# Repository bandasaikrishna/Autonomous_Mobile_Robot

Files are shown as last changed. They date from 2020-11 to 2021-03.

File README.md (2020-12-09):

## Autonomous Navigation Mobile Robot using ROS Navigation Stack.
Watch the video tutorial [here .](https://youtu.be/Uz_i_sjVhIM)
Website documentation [here.](https://www.rosroboticslearning.com/)

AMCL is used for localisation, with DWA local planner planner for path planning.

### Sensors used:
1. RP Lidar A1-M8.
2. Motor Encoders.

### Other parts:
1. Nvidia Jetson Nano 4gb.
2. 2x Arduino nano (One for each motor to make sure smooth operation of Interrupt service routine to count the encoder pulses and ROS communication over I2C.)
3. Encoder motors [Link Here](https://robokits.co.in/motors/rhino-gb37-12v-dc-geared-motor/dc-12v-encoder-servo-motors/rhino-gb37-12v-60rpm-10.4kgcm-dc-geared-encoder-servo-motor)
4. Robot Chasis
5. Boost converter to provide 12V for motors.

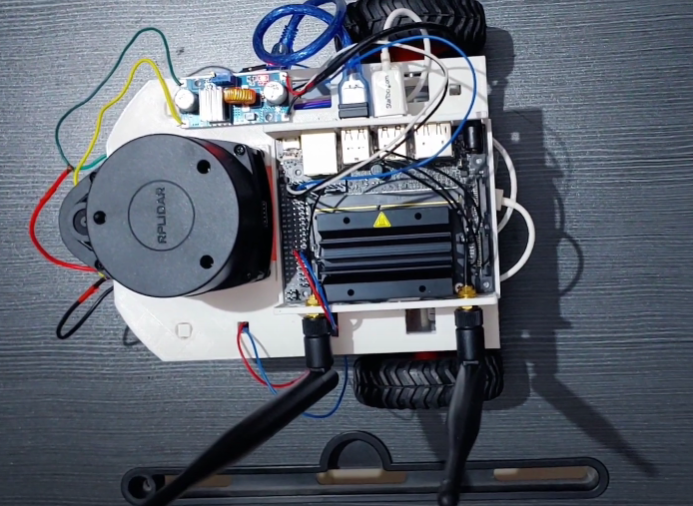
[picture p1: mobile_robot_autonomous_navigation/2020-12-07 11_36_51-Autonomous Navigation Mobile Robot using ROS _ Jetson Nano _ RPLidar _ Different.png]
Jetson Nano and LiDAR

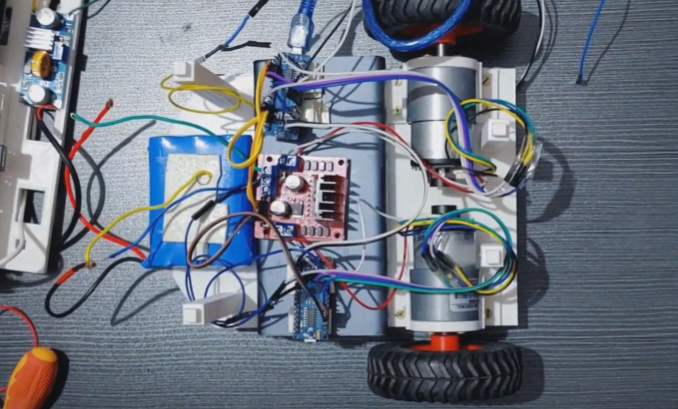
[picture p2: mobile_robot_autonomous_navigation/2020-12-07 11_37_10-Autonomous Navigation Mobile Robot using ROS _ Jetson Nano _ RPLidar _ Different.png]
Arduinos and motors


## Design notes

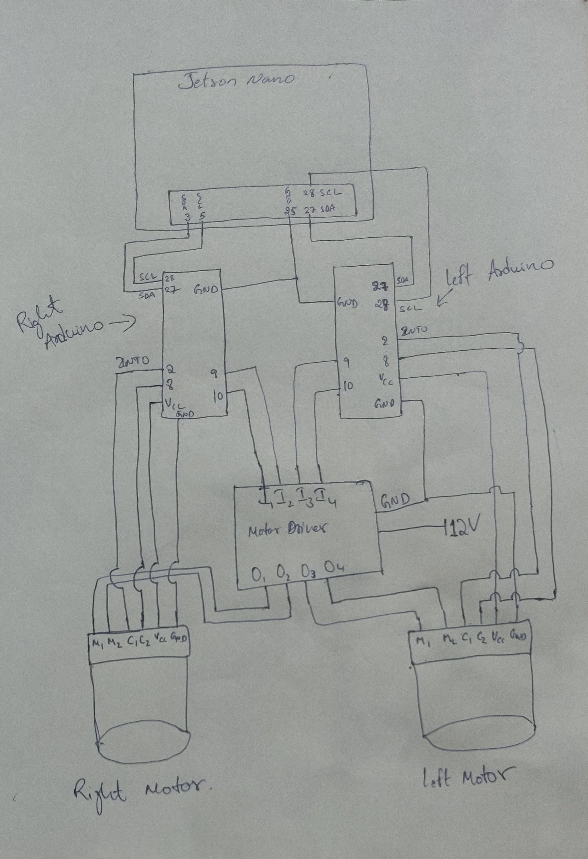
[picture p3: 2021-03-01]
mobile_robot_autonomous_navigation/Connection_Diagram.jpg

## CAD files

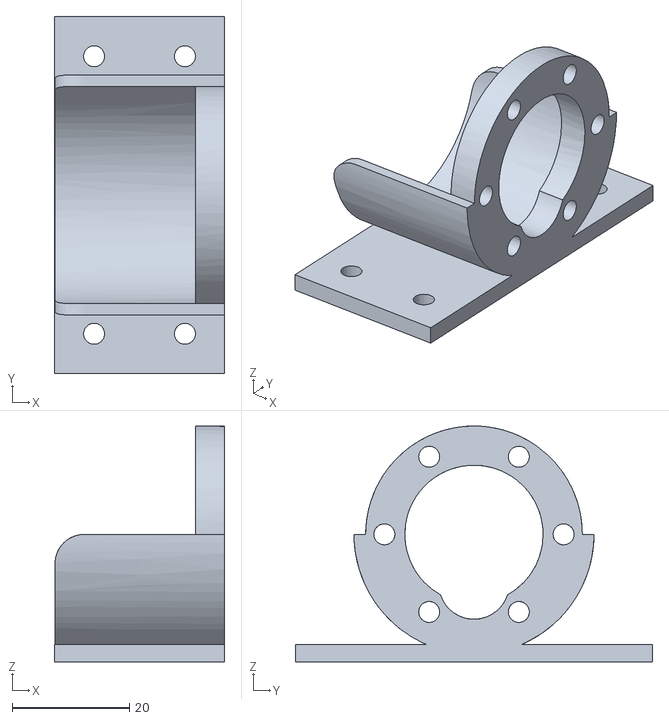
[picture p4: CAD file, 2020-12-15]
3D_Model_Files/Mobile_robot_Motor_case.stl
29.1 x 61.0 x 40.3

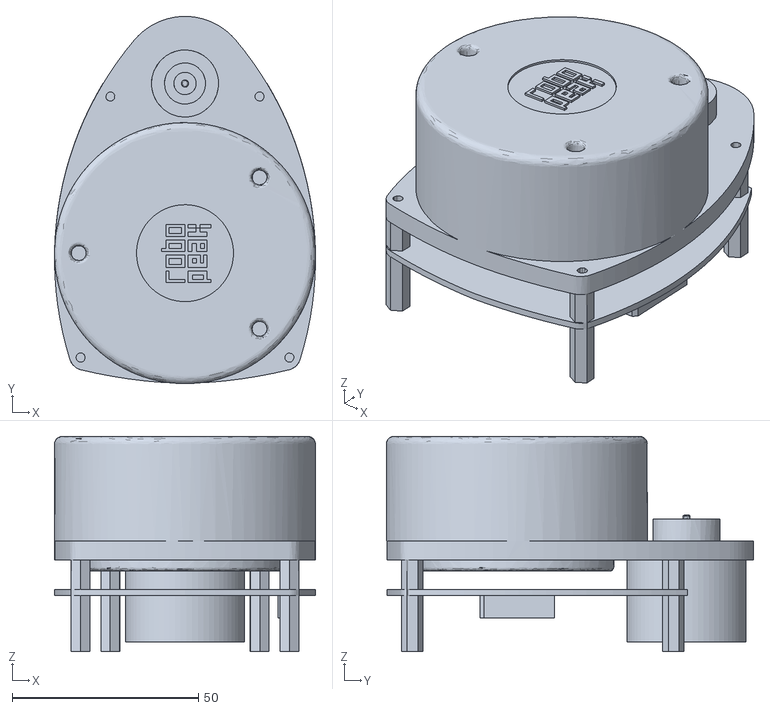
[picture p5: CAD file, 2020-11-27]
mobile_robot_autonomous_navigation/stl/RpLidar.stl
70.0 x 98.5 x 57.7

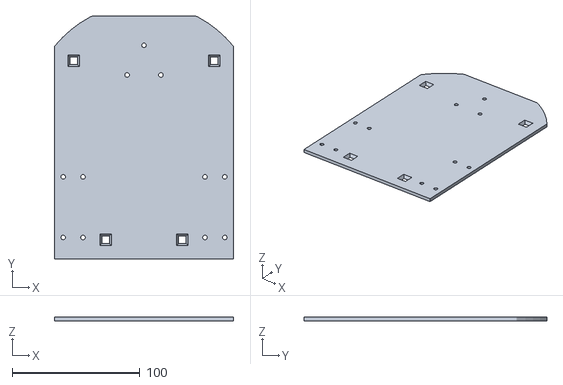
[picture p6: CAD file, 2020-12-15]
3D_Model_Files/Mobile_robot_base.stl
140.0 x 190.0 x 3.00

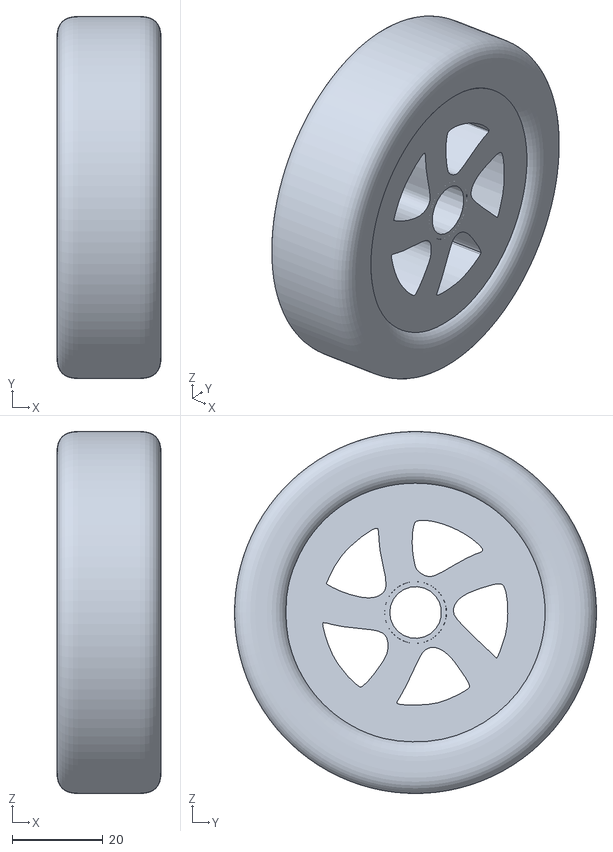
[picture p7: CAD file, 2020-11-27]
mobile_robot_autonomous_navigation/stl/Wheel.stl
23.0 x 80.0 x 80.0

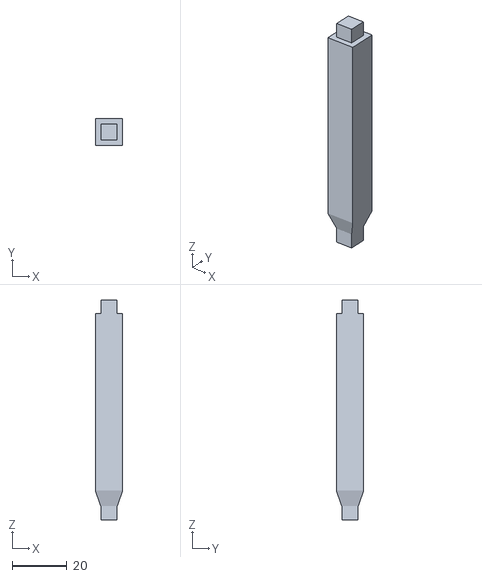
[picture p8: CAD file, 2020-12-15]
3D_Model_Files/Support_rod.stl
10.0 x 10.0 x 80.0

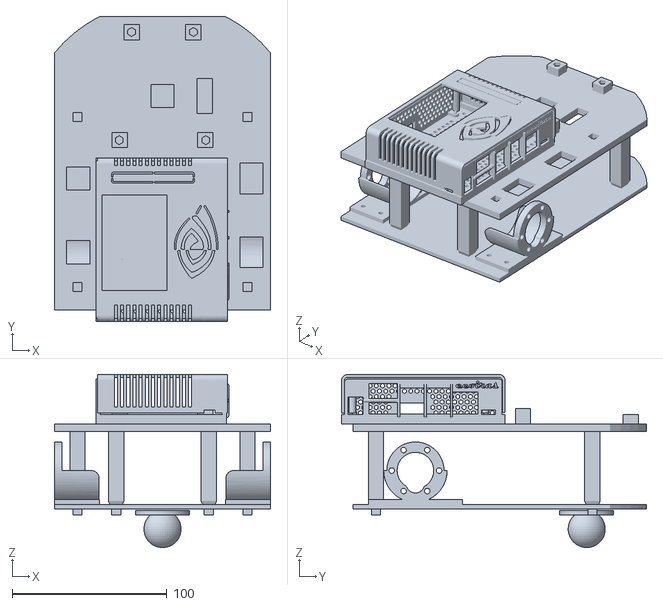
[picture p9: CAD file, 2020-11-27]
mobile_robot_autonomous_navigation/stl/Chasis.stl
140.0 x 197.3 x 112.0

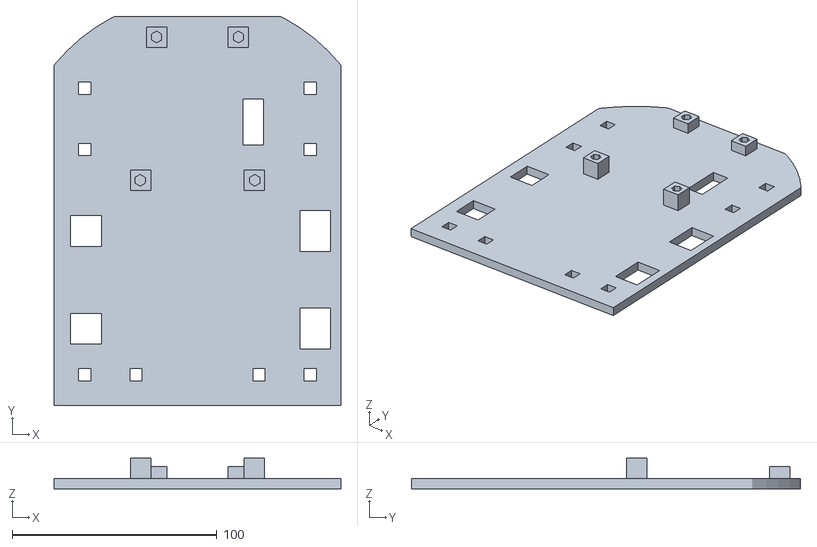
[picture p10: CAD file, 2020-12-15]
3D_Model_Files/Mobile_robot_2nd_base.stl
140.0 x 190.0 x 15.0

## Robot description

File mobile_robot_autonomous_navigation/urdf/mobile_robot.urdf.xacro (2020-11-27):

<?xml version="1.0"?>
<robot name="mobile_robot" xmlns:xacro="http://ros.org/wiki/xacro">

    <material name="blue">
	    <color rgba="0 0 0.8 1"/>
    </material>

    <material name="white">
	    <color rgba="1 1 1 1"/>
    </material>

    <material name="black">
	    <color rgba="0 0 0 1"/>
    </material>

    <material name="green">
        <color rgba="0.0 0.8 0.0 1.0"/>
    </material>

    <link name="base_link">
        <!--<visual>
          <geometry>
             <box size="0.24 0.24 0.001"/>
          </geometry>
          <material name="white"/>
          <origin rpy="0 0 0" xyz="0 0 0.0005"/>
          <material>
            <color rgba="0 0 0.8 1" />
          </material>
        </visual> -->
        <collision>
          <origin rpy="0 0 0" xyz="0 0 0.0005"/>
          <geometry>
            <box size="0.22 0.22 0.001"/>
          </geometry>
        </collision>
    </link>

    <joint name="base_link_joint" type="fixed">
        <origin xyz="0 0 0.026" rpy="0 0 -1.5708" />
        <parent link="base_link" />
        <child link="base_plate" />
    </joint>

    <link name="base_plate">
    <visual>
      <origin rpy="0 0 0" xyz="0.03 0 -0.026"/>
      <geometry>
        <mesh filename="package://mobile_robot_autonomous_navigation/stl/Chasis.stl" scale="0.001 0.001 0.001"/> 
      </geometry>
      <material name="white"/>
    </visual>
    <collision>
      <origin rpy="0 0 0" xyz="0.03 0 -0.026" />
      <geometry>
        <mesh filename="package://mobile_robot_autonomous_navigation/stl/Chasis.stl" scale="0.001 0.001 0.001" />
      </geometry>
    </collision>
    </link>   
    
    
    <joint name="right_wheel_joint" type="continuous">
        <origin xyz="-0.08 -0.06 0.015" rpy="0 0 0" />
        <parent link="base_plate" />
        <child link="right_wheel" />
        <axis xyz="-1 0 0" />
    </joint>

    <link name="right_wheel">
    <visual>
      <origin rpy="0 0 0" xyz="0.11 0.059 -0.04"/>
      <geometry>
        <mesh filename="package://mobile_robot_autonomous_navigation/stl/Wheel.stl" scale="0.001 0.001 0.001"/> 
      </geometry>
      <material name="black"/>
    </visual>
    <collision>
      <origin rpy="0 0 0" xyz="0.11 0.059 -0.04"/>
      <geometry>
        <mesh filename="package://mobile_robot_autonomous_navigation/stl/Wheel.stl" scale="0.001 0.001 0.001" />
      </geometry>
    </collision>
    </link>   
    
    <joint name="left_wheel_joint" type="continuous">
        <origin xyz="0.08 -0.06 0.015" rpy="0 0 0" />
        <parent link="base_plate" />
        <child link="left_wheel" />
        <axis xyz="-1 0 0" />
    </joint>

    <link name="left_wheel">
    <visual>
      <origin rpy="0 0 0" xyz="0.133 0.059 -0.04"/>
      <geometry>
        <mesh filename="package://mobile_robot_autonomous_navigation/stl/Wheel.stl" scale="0.001 0.001 0.001"/> 
      </geometry>
      <material name="black"/>
    </visual>
    <collision>
      <origin rpy="0 0 0" xyz="0.133 0.059 -0.04"/>
      <geometry>
        <mesh filename="package://mobile_robot_autonomous_navigation/stl/Wheel.stl" scale="0.001 0.001 0.001" />
      </geometry>
    </collision>
    </link>   
    
    <joint name="laser_joint" type="fixed">
        <origin xyz="0 0.040 0.090" rpy="0 0 1.5708" />
        <parent link="base_plate" />
        <child link="laser" />
    </joint>

    <link name="laser">
    <visual>
      <origin rpy="0 0 -1.5708" xyz="0.084 -0.242 -0.098"/>
      <geometry>
        <mesh filename="package://mobile_robot_autonomous_navigation/stl/RpLidar.stl" scale="0.001 0.001 0.001"/> 
      </geometry>
      <material name="blue"/>
    </visual>
    <collision>
      <origin rpy="0 0 0" xyz="0.242 0.084 -0.098" />
      <geometry>
        <mesh filename="package://mobile_robot_autonomous_navigation/stl/RpLidar.stl" scale="0.001 0.001 0.001" />
      </geometry>
    </collision>
    </link>  
    
</robot>

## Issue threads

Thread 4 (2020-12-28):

Issues in case of controller_check.launch

vijaybande, 2020-12-28:
while running controller_check.launch I am getting
" Device File not available. Aborting read"

yuki-ubuntu, 2021-03-19:
I am also suffering from the same error.

```
... logging to /home/user/.ros/log/24fe7864-888a-11eb-bda4-bb6933ebd3a4/roslaunch-user-3515.log
Checking log directory for disk usage. This may take a while.
Press Ctrl-C to interrupt
Done checking log file disk usage. Usage is <1GB.

started roslaunch server http://user:39347/

SUMMARY
========

PARAMETERS
 * /joint_limits/left_wheel_joint/has_acceleration_limits: False
 * /joint_limits/left_wheel_joint/has_effort_limits: False
 * /joint_limits/left_wheel_joint/has_jerk_limits: False
 * /joint_limits/left_wheel_joint/has_position_limits: False
 * /joint_limits/left_wheel_joint/has_velocity_limits: True
 * /joint_limits/left_wheel_joint/max_acceleration: 0.0
 * /joint_limits/left_wheel_joint/max_effort: 0
 * /joint_limits/left_wheel_joint/max_jerk: 0
 * /joint_limits/left_wheel_joint/max_position: 0
 * /joint_limits/left_wheel_joint/max_velocity: 2.62
 * /joint_limits/left_wheel_joint/min_effort: 0
 * /joint_limits/left_wheel_joint/min_position: 0
 * /joint_limits/left_wheel_joint/min_velocity: -2.62
 * /joint_limits/right_wheel_joint/has_acceleration_limits: False
 * /joint_limits/right_wheel_joint/has_effort_limits: False
 * /joint_limits/right_wheel_joint/has_jerk_limits: False
 * /joint_limits/right_wheel_joint/has_position_limits: False
 * /joint_limits/right_wheel_joint/has_velocity_limits: True
 * /joint_limits/right_wheel_joint/max_acceleration: 0.0
 * /joint_limits/right_wheel_joint/max_effort: 0
 * /joint_limits/right_wheel_joint/max_jerk: 0
 * /joint_limits/right_wheel_joint/max_position: 0
 * /joint_limits/right_wheel_joint/max_velocity: 2.62
 * /joint_limits/right_wheel_joint/min_effort: 0
 * /joint_limits/right_wheel_joint/min_position: 0
 * /joint_limits/right_wheel_joint/min_velocity: -2.62
 * /mobile_robot/joints_update/publish_rate: 50
 * /mobile_robot/joints_update/type: joint_state_contr...
 * /mobile_robot/mobile_base_controller/angular/z/has_acceleration_limits: True
 * /mobile_robot/mobile_base_controller/angular/z/has_jerk_limits: True
 * /mobile_robot/mobile_base_controller/angular/z/has_velocity_limits: True
 * /mobile_robot/mobile_base_controller/angular/z/max_acceleration: 0.5
 * /mobile_robot/mobile_base_controller/angular/z/max_jerk: 1
 * /mobile_robot/mobile_base_controller/angular/z/max_velocity: 1.0472
 * /mobile_robot/mobile_base_controller/base_frame_id: base_link
 * /mobile_robot/mobile_base_controller/cmd_vel_timeout: 0.25
 * /mobile_robot/mobile_base_controller/left_wheel: left_wheel_joint
 * /mobile_robot/mobile_base_controller/linear/x/has_acceleration_limits: True
 * /mobile_robot/mobile_base_controller/linear/x/has_jerk_limits: False
 * /mobile_robot/mobile_base_controller/linear/x/has_velocity_limits: True
 * /mobile_robot/mobile_base_controller/linear/x/max_acceleration: 0.025
 * /mobile_robot/mobile_base_controller/linear/x/max_jerk: 2.0
 * /mobile_robot/mobile_base_controller/linear/x/max_velocity: 0.1
 * /mobile_robot/mobile_base_controller/linear/x/min_acceleration: -0.025
 * /mobile_robot/mobile_base_controller/linear/x/min_velocity: -0.1
 * /mobile_robot/mobile_base_controller/pose_covariance_diagonal: [0.001, 0.001, 10...
 * /mobile_robot/mobile_base_controller/publish_rate: 50.0
 * /mobile_robot/mobile_base_controller/right_wheel: right_wheel_joint
 * /mobile_robot/mobile_base_controller/twist_covariance_diagonal: [0.001, 0.001, 10...
 * /mobile_robot/mobile_base_controller/type: diff_drive_contro...
 * /mobile_robot/mobile_base_controller/wheel_radius: 0.04
 * /mobile_robot/mobile_base_controller/wheel_radius_multiplier: 1.0
 * /mobile_robot/mobile_base_controller/wheel_separation: 0.18
 * /mobile_robot/mobile_base_controller/wheel_separation_multiplier: 1.0
 * /robot_description: <?xml version="1....
 * /rosdistro: noetic
 * /rosversion: 1.15.9

NODES
  /
    controller_spawner (controller_manager/spawner)
    robot_hardware_interface (mobile_robot_autonomous_navigation/mobile_robot_hardware_interface)
    robot_state_publisher (robot_state_publisher/robot_state_publisher)
    rviz (rviz/rviz)

auto-starting new master
process[master]: started with pid [3525]
ROS_MASTER_URI=http://localhost:11311

setting /run_id to 24fe7864-888a-11eb-bda4-bb6933ebd3a4
process[rosout-1]: started with pid [3535]
started core service [/rosout]
process[robot_hardware_interface-2]: started with pid [3542]
process[robot_state_publisher-3]: started with pid [3543]
process[rviz-4]: started with pid [3544]
[ERROR] [1616141251.262584453]: Couldn't open I2C Bus 0 [openfd():open 2]
[ERROR] [1616141251.269328046]: I2C slave 8 failed [openfd():ioctl 9]
[ERROR] [1616141251.269863482]: Couldn't open I2C Bus 1 [openfd():open 13]
[ERROR] [1616141251.269956203]: I2C slave 9 failed [openfd():ioctl 9]
process[controller_spawner-5]: started with pid [3550]
[ERROR] [1616141251.627434753]: Device File not available. Aborting read
[ERROR] [1616141251.627596250]: Device File not available. Aborting read
[ERROR] [1616141251.727291223]: Device File not available. Aborting read
[ERROR] [1616141251.727414425]: Device File not available. Aborting read
[ERROR] [1616141251.827256932]: Device File not available. Aborting read
[ERROR] [1616141251.827378319]: Device File not available. Aborting read
[ERROR] [1616141251.927267288]: Device File not available. Aborting read
[ERROR] [1616141251.927386768]: Device File not available. Aborting read
[ERROR] [1616141252.027304718]: Device File not available. Aborting read
[ERROR] [1616141252.027452679]: Device File not available. Aborting read
[ERROR] [1616141252.127297723]: Device File not available. Aborting read
[ERROR] [1616141252.127428758]: Device File not available. Aborting read
[INFO] [1616141252.200992]: Controller Spawner: Waiting for service controller_manager/load_controller
[INFO] [1616141252.213016]: Controller Spawner: Waiting for service controller_manager/switch_controller
[INFO] [1616141252.221809]: Controller Spawner: Waiting for service controller_manager/unload_controller
[ERROR] [1616141252.227358005]: Device File not available. Aborting read
[ERROR] [1616141252.227487373]: Device File not available. Aborting read
[INFO] [1616141252.231349]: Loading controller: /mobile_robot/joints_update
[ERROR] [1616141252.327259567]: Device File not available. Aborting read
[ERROR] [1616141252.327395102]: Device File not available. Aborting read
[INFO] [1616141252.328758]: Loading controller: /mobile_robot/mobile_base_controller
[ INFO] [1616141252.355144534]: Controller state will be published at 50Hz.
[ INFO] [1616141252.359806625]: Wheel separation will be multiplied by 1.
[ INFO] [1616141252.362829204]: Left wheel radius will be multiplied by 1.
[ INFO] [1616141252.362979591]: Right wheel radius will be multiplied by 1.
[ INFO] [1616141252.364939781]: Velocity rolling window size of 10.
[ INFO] [1616141252.368063359]: Velocity commands will be considered old if they are older than 0.25s.
[ INFO] [1616141252.370372969]: Allow mutiple cmd_vel publishers is enabled
[ INFO] [1616141252.373841894]: Base frame_id set to base_link
[ INFO] [1616141252.375285296]: Odometry frame_id set to odom
[ INFO] [1616141252.377349336]: Publishing to tf is enabled
[ERROR] [1616141252.427276016]: Device File not available. Aborting read
[ERROR] [1616141252.427424013]: Device File not available. Aborting read
[ INFO] [1616141252.430225838]: Odometry params : wheel separation 0.18, left wheel radius 0.04, right wheel radius 0.04
[ INFO] [1616141252.437641994]: Adding left wheel with joint name: left_wheel_joint and right wheel with joint name: right_wheel_joint
[ INFO] [1616141252.477879388]: Dynamic Reconfigure:
DynamicParams:
	Odometry parameters:
		left wheel radius multiplier: 1
		right wheel radius multiplier: 1
		wheel separation multiplier: 1
	Publication parameters:
		Publish executed velocity command: disabled
		Publication rate: 50
		Publish frame odom on tf: enabled
[ERROR] [1616141252.527265299]: Device File not available. Aborting read
[ERROR] [1616141252.527408167]: Device File not available. Aborting read
[INFO] [1616141252.528493]: Controller Spawner: Loaded controllers: /mobile_robot/joints_update, /mobile_robot/mobile_base_controller
[ERROR] [1616141252.627321803]: Device File not available. Aborting read
[ERROR] [1616141252.627481930]: Device File not available. Aborting read
[INFO] [1616141252.628878]: Started controllers: /mobile_robot/joints_update, /mobile_robot/mobile_base_controller
[ERROR] [1616141252.727312585]: Device File not available. Aborting read
[ERROR] [1616141252.727488953]: Device File not available. Aborting read

```

If you have a solution, I would appreciate it if you could let me know.

vijaybande, 2021-04-08:
this issues resolved

mehmetaksu2034, 2021-05-20:
Hi, how can you solve this problem? Can you help me pls.

vijaybande, 2021-05-21:
Kindly check your i2c buses are available or not??

On Fri, 21 May, 2021, 4:29 am mehmetaksu2034, ***@***.***>
wrote:

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

Closed 2021-04-08.

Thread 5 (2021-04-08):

Remote I/O error. Failed to write to I2C Slave 0x8 @ [write_byte():write 121], Could not read from I2C slave 0x8, [read_byte():read 121]

vijaybande, 2021-04-08:
I am gettig below errros while running controller_check.launch. i2c slaves 0x08 and 0x09 were detected on Rpi

[ERROR] [1617861674.244743164]: Could not read from I2C slave 0x8, [read_byte():read 121]
[ERROR] [1617861674.252197838]: Could not read from I2C slave 0x9, [read_byte():read 121]
[ERROR] [1617861674.252879451]: Remote I/O error. Failed to write to I2C Slave 0x8 @ [write_byte():write 121]
[ERROR] [1617861674.253275023]: Remote I/O error. Failed to write to I2C Slave 0x9 @ [write_byte():write 121]
[ERROR] [1617861674.344301937]: Could not read from I2C slave 0x8, [read_byte():read 121]
[ERROR] [1617861674.345627664]: Could not read from I2C slave 0x9, [read_byte():read 121]
[ERROR] [1617861674.444579302]: Could not read from I2C slave 0x8, [read_byte():read 121]
[ERROR] [1617861674.446186018]: Could not read from I2C slave 0x9, [read_byte():read 121]
[ERROR] [1617861674.544354689]: Could not read from I2C slave 0x8, [read_byte():read 121]
[ERROR] [1617861674.546916455]: Could not read from I2C slave 0x9, [read_byte():read 121]
[ERROR] [1617861674.644397524]: Could not read from I2C slave 0x8, [read_byte():read 121]
[ERROR] [1617861674.645817938]: Could not read from I2C slave 0x9, [read_byte():read 121]
[ERROR] [1617861674.744349213]: Could not read from I2C slave 0x8, [read_byte():read 121]

vijaybande, 2021-04-20:
Resolved.

audricsaragih, 2021-05-13:
Could you tell me please how you solved this?

vijaybande, 2021-05-13:
1.) Make sure that the both i2c are enabled on the board i.e i2c-0 and i2c-
1
2.) Connect the arduino slave 08 to i2c-0 and arduino slave 09 to i2c-1

But may I know how it is working in the link given below ??
https://youtu.be/Uz_i_sjVhIM

On Thu, 13 May, 2021, 3:13 pm audricsaragih, ***@***.***>
wrote:

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

audricsaragih, 2021-05-13:
Yes I've done that both.
But when i run :

> i2cdetect -y 0

or

> i2cdetect -y 1

It didn't catch any adress
I'm stuck there too

vijaybande, 2021-05-13:
Are u using raspberry pi or Jetson nano??

On Thu, 13 May, 2021, 4:36 pm audricsaragih, ***@***.***>
wrote:

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

vijaybande, 2021-05-13:
Can we connect over the call??

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

audricsaragih, 2021-05-13:
I'm using Raspberry Pi.
Sure, you can email me first at audric.saragih@gmail.com

robotos2023, 2022-12-07:
I got the same error. I am using Raspberry pi 4 model b. Can you please tell me how you do it? I'd appreciate it a lot!

jomar04, 2023-05-25:
Can I ask how you resolve it?

Rithikrkm, 2025-03-10:
Bro Im having the same issue and I've been stuck here for a while, can you pls share how u resolved this issue

Closed 2021-04-20.

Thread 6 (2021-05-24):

Navigation without encoder

mehmetaksu2034, 2021-05-24:
Hi, thanks for sharing this nice project. can I use yours navigation stack in my robot that has not any encoder?

mehmetaksu2034, 2021-05-28:
Yes, it is possible.

Kuhan96, 2021-06-01:
@mehmetaksu2034
Hello can I know how you perform this without using motor with encoders? thank you

mehmetaksu2034, 2021-06-01:
I used laser scan matcher technique for gmapping and localisation (amcl). Then I changed the config file that shared here according to its own robot. And finally, by running the move_base.launch file, I can make the navigation process.

Closed 2021-05-28.

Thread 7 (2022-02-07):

Few questions from your existing setup

Arvrairobo, 2022-02-07:
I have seen you are using DC gear encoder motor from robokits but i can see from the video, it is literally zero noise? how is that possible? i have seen in the arduino code, you have written like:

  TCCR1B = TCCR1B & 0b11111000 | 1;                   // set 31KHz PWM to prevent motor noise

what does it do? you dont have any noise because of this? or am i missing something?

my motor is very loud and noisy so i thought i should not use DC bruss motor and instead going to brushless motor but it is again a costly setup, so let me know if it is really possible to supress the noise?

Thanks

Arvrairobo, 2022-02-16:
@bandasaikrishna @0xraks can anyone help?

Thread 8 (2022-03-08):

Change in wheel and motor rpm

niranjan1997, 2022-03-08:
I have a different motor the rpm is around 100 per mi
And the wheel dia is 50mm.  Where do I change these values because these factors impact the odometry right.

mohitoshjc, 2022-09-06:
did you figure out, the solution for this?

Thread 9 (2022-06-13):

I am gettig below errros while running controller_check.launch. i2c slaves 0x08 and 0x09 were detected on Rpi and Im using raspberry pi 4

gndeepan, 2022-06-13:
[ERROR] [1617861674.244743164]: Could not read from I2C slave 0x8, [read_byte():read 121]
[ERROR] [1617861674.252197838]: Could not read from I2C slave 0x9, [read_byte():read 121]
[ERROR] [1617861674.252879451]: Remote I/O error. Failed to write to I2C Slave 0x8 @ [write_byte():write 121]
[ERROR] [1617861674.253275023]: Remote I/O error. Failed to write to I2C Slave 0x9 @ [write_byte():write 121]
[ERROR] [1617861674.344301937]: Could not read from I2C slave 0x8, [read_byte():read 121]
[ERROR] [1617861674.345627664]: Could not read from I2C slave 0x9, [read_byte():read 121]
[ERROR] [1617861674.444579302]: Could not read from I2C slave 0x8, [read_byte():read 121]
[ERROR] [1617861674.446186018]: Could not read from I2C slave 0x9, [read_byte():read 121]
[ERROR] [1617861674.544354689]: Could not read from I2C slave 0x8, [read_byte():read 121]
[ERROR] [1617861674.546916455]: Could not read from I2C slave 0x9, [read_byte():read 121]
[ERROR] [1617861674.644397524]: Could not read from I2C slave 0x8, [read_byte():read 121]
[ERROR] [1617861674.645817938]: Could not read from I2C slave 0x9, [read_byte():read 121]
[ERROR] [1617861674.744349213]: Could not read from I2C slave 0x8, [read_byte():read 121]

gndeepan, 2022-06-14:
I solved this error but rviz robot model not moving but motors running perfectly not moving 3d model any one plz solve this error

315haoge, 2022-12-01:
> I solved this error but rviz robot model not moving but motors running perfectly not moving 3d model any one plz solve this error

Hi, could you please help me how to solve this problem? Thank you.

robotos2023, 2022-12-07:
Same issues. Would you please help us to solve this problem. Thank yoi!

Rithikrkm, 2025-03-10:
[ERROR] [1617861674.252197838]: Could not read from I2C slave 0x9, [read_byte():read 121]

Im stuck with the above issue, would you please share on how u fixed this prblm

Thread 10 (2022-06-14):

rviz robot model not moving

gndeepan, 2022-06-14:
rviz robot model not moving but motors running perfectly not moving 3d model any one plz solve this error

Rithikrkm, 2025-03-17:
Hi bro I'm having somewhat similar issue, my robot keeps spinning while running controller check, I swapped the motors but nothing seems to help, can you help me out to solve the problem

Closed 2022-06-22.

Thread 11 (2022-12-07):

Errors in I2C slaves 0x08 and 0x09 on Raspberry Pi and Arduino Nano V3

robotos2023, 2022-12-07:
[ERROR] [1617861674.244743164]: Could not read from I2C slave 0x8, [read_byte():read 121]
[ERROR] [1617861674.252197838]: Could not read from I2C slave 0x9, [read_byte():read 121]
[ERROR] [1617861674.252879451]: Remote I/O error. Failed to write to I2C Slave 0x8 @ [write_byte():write 121]
[ERROR] [1617861674.253275023]: Remote I/O error. Failed to write to I2C Slave 0x9 @ [write_byte():write 121]

Please help me to solve this issue. Thank you!

jeonsion, 2023-03-23:
Do not use RX pins

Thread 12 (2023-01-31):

can not move it properly using teleop keyboard + the robot in Rviz keeps spinning

sudoNass, 2023-01-31:
when using the teleop twist keyboard, the robot isn't moving properly.
sometimes all the buttons move it in the same direction or randomly.
and after launching the "controller check" file or the "auto nav" the robot spinning and ignoring my nav goal.

Rithikrkm, 2025-03-11:
Bro Im having the same issue, please share if u were able to solve the problem

Rithikrkm, 2025-03-11:
Ok bro, thanks for the reply, ill check my batteries

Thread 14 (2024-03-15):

I2C can't read error

Abishakinbanathan, 2024-03-15:

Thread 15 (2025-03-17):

Only one motor responding while launching controller check launch file and it keeps spinning

Rithikrkm, 2025-03-17:
While launching the controller check file, only one motor responds while inputting i using rostopic keyboard. I haven't connected the RPLiDAR. Tried swapping the motors and swapping arduino nano but nothing seems to work. Please help me out

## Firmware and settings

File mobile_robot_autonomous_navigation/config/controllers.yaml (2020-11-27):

mobile_robot:

    joints_update:
      type: joint_state_controller/JointStateController
      publish_rate: 50

    mobile_base_controller:
      type        : "diff_drive_controller/DiffDriveController"
      left_wheel  : 'left_wheel_joint'
      right_wheel : 'right_wheel_joint'
      publish_rate: 50.0               # default: 50
      pose_covariance_diagonal : [0.001, 0.001, 1000000.0, 1000000.0, 1000000.0, 1000.0]
      twist_covariance_diagonal: [0.001, 0.001, 1000000.0, 1000000.0, 1000000.0, 1000.0]

      # Wheel separation and diameter. These are both optional.
      # diff_drive_controller will attempt to read either one or both from the
      # URDF if not specified as a parameter
      wheel_separation : 0.180
      wheel_radius : 0.04

      # Wheel separation and radius multipliers
      wheel_separation_multiplier: 1.0 # default: 1.0
      wheel_radius_multiplier    : 1.0 # default: 1.0

      # Velocity commands timeout [s], default 0.5
      cmd_vel_timeout: 0.25

      # Base frame_id
      base_frame_id: "base_link"

      # Velocity and acceleration limits
      # Whenever a min_* is unspecified, default to -max_*
      linear:
        x:
          has_velocity_limits    : true
          max_velocity           : 0.10  # m/s
          min_velocity           : -0.10 # m/s
          has_acceleration_limits: true
          max_acceleration       : 0.025  # m/s^2
          min_acceleration       : -0.025 # m/s^2
          has_jerk_limits        : false
          max_jerk               : 2.0  # m/s^3
      angular:
        z:
          has_velocity_limits    : true
          max_velocity           : 1.0472  # rad/s
          has_acceleration_limits: true
          max_acceleration       : 0.5  # rad/s^2
          has_jerk_limits        : true
          max_jerk               : 1 # rad/s^3

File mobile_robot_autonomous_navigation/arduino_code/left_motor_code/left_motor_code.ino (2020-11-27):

// PID motor position control.
// Thanks to Brett Beauregard for his nice PID library http://brettbeauregard.com/blog/2011/04/improving-the-beginners-pid-introduction/

#include <PinChangeInt.h>
#include <Wire.h>
#include <PID_v1.h>
#define encodPinA1      2                       // Quadrature encoder A pin
#define encodPinB1      8                       // Quadrature encoder B pin
#define M1              9                       // PWM outputs to L298N H-Bridge motor driver module
#define M2              10

double kp =1, ki =20 , kd =0;             // modify for optimal performance
double input = 0, output = 0, setpoint = 0;
unsigned long lastTime,now;
volatile long encoderPos = 0,last_pos=0,lastpos=0;
PID myPID(&input, &output, &setpoint, kp, ki, kd,DIRECT);  
void setup() {
  pinMode(encodPinA1, INPUT_PULLUP);                  // quadrature encoder input A
  pinMode(encodPinB1, INPUT_PULLUP);                  // quadrature encoder input B
  attachInterrupt(0, encoder, FALLING);               // update encoder position
  TCCR1B = TCCR1B & 0b11111000 | 1;                   // To prevent Motor Noise
  
  myPID.SetMode(AUTOMATIC);
  myPID.SetSampleTime(1);
  myPID.SetOutputLimits(-255, 255);
  
  Wire.begin(8);                // join i2c bus with address #8 for Right Motor
  Wire.onRequest(requestEvent); // register events
  Wire.onReceive(receiveEvent);
  //Serial.begin (9600); 
  
}

void loop() {
   now = millis();
   int timeChange = (now - lastTime);
   if(timeChange>=500 )
   {
      input = (360.0*1000*(encoderPos-last_pos)) /(1856.0*(now - lastTime));
      lastTime=now;
      last_pos=encoderPos;
   }
  
  myPID.Compute();                                    // calculate new output
  pwmOut(output);                                     // drive L298N H-Bridge module
  delay(10);
}

void pwmOut(int out) {                                // to H-Bridge board
  if (out > 0) {
    analogWrite(M1, out);                             // drive motor CW
    analogWrite(M2, 0);
  }
  else {
    analogWrite(M1, 0);
    analogWrite(M2, abs(out));                        // drive motor CCW
  }
}

void encoder()  {                                     // pulse and direction, direct port reading to save cycles  
  if (PINB & 0b00000001)    encoderPos--;             // if(digitalRead(encodPinB1)==HIGH)   count --;
  else                      encoderPos++;             // if(digitalRead(encodPinB1)==LOW)   count ++;
}

void requestEvent() {
  int8_t s;
  
  s= (360.0*(encoderPos-lastpos))/1856.0; //change in position in degrees of the wheel
  lastpos=encoderPos;
  Wire.write(s); // respond with message of 6 bytes
}


// function that executes whenever data is received from master
// this function is registered as an event, see setup()
void receiveEvent(int howMany)
{
  uint8_t a,b;
  a = Wire.read();
  b = Wire.read();
  setpoint= (double)((b<<8)|a);
  //Serial.println((uint8_t)a);
  //Serial.println((uint8_t)b);
  
  //Serial.println(setpoint);
}

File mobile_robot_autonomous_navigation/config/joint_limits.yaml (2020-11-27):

joint_limits:
    right_wheel_joint:
      has_position_limits: false
      min_position: 0
      max_position: 0
      has_velocity_limits: true
      max_velocity: 2.62
      min_velocity: -2.62
      has_acceleration_limits: false
      max_acceleration: 0.0
      has_jerk_limits: false
      max_jerk: 0
      has_effort_limits: false
      max_effort: 0
      min_effort: 0
    
    left_wheel_joint:
      has_position_limits: false
      min_position: 0
      max_position: 0
      has_velocity_limits: true
      max_velocity: 2.62
      min_velocity: -2.62
      has_acceleration_limits: false
      max_acceleration: 0.0
      has_jerk_limits: false
      max_jerk: 0
      has_effort_limits: false
      max_effort: 0
      min_effort: 0

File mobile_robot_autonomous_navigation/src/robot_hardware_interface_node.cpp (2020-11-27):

#include <mobile_robot_autonomous_navigation/robot_hardware_interface.h>

//namesapce i2c_ros

ROBOTHardwareInterface::ROBOTHardwareInterface(ros::NodeHandle& nh) : nh_(nh) {
    init();

    controller_manager_.reset(new controller_manager::ControllerManager(this, nh_));
    loop_hz_=10;
    ros::Duration update_freq = ros::Duration(1.0/loop_hz_);
	
	
    non_realtime_loop_ = nh_.createTimer(update_freq, &ROBOTHardwareInterface::update, this);
}

ROBOTHardwareInterface::~ROBOTHardwareInterface() {
}

void ROBOTHardwareInterface::init() {
	
	for(int i=0; i<2; i++)
	{
	// Create joint state interface
        hardware_interface::JointStateHandle jointStateHandle(joint_name_[i], &joint_position_[i], &joint_velocity_[i], &joint_effort_[i]);
        joint_state_interface_.registerHandle(jointStateHandle);
       
    // Create velocity joint interface
	    hardware_interface::JointHandle jointVelocityHandle(jointStateHandle, &joint_velocity_command_[i]);
        velocity_joint_interface_.registerHandle(jointVelocityHandle);

    // Create Joint Limit interface   
        joint_limits_interface::JointLimits limits;
        joint_limits_interface::getJointLimits(joint_name_[i], nh_, limits);
	    joint_limits_interface::VelocityJointSaturationHandle jointLimitsHandle(jointVelocityHandle, limits);
	    velocityJointSaturationInterface.registerHandle(jointLimitsHandle);

	}
    
// Register all joints interfaces    
    registerInterface(&joint_state_interface_);
    registerInterface(&velocity_joint_interface_);
    registerInterface(&velocityJointSaturationInterface);
}

void ROBOTHardwareInterface::update(const ros::TimerEvent& e) {
    elapsed_time_ = ros::Duration(e.current_real - e.last_real);
    read();
    controller_manager_->update(ros::Time::now(), elapsed_time_);
    write(elapsed_time_);
}

void ROBOTHardwareInterface::read() {
    uint8_t rbuff[1];
    int x;

    left_motor.readBytes(rbuff,1);
    x=(int8_t)rbuff[0];
    left_motor_pos+=angles::from_degrees((double)x);
    joint_position_[0]=left_motor_pos;

    right_motor.readBytes(rbuff,1);
    x=(int8_t)rbuff[0];
    right_motor_pos+=angles::from_degrees((double)x);
    joint_position_[1]=right_motor_pos;

    //ROS_INFO("pos=%.2f x=%d ",pos,x);
	
}

void ROBOTHardwareInterface::write(ros::Duration elapsed_time) {
   
    velocityJointSaturationInterface.enforceLimits(elapsed_time);   

	uint8_t wbuff[2];

    int velocity,result;
    
    
    velocity=(int)angles::to_degrees(joint_velocity_command_[0]);
	wbuff[0]=velocity;
    wbuff[1]=velocity >> 8;
	//ROS_INFO("joint_velocity_command_[0]=%.2f velocity=%d  B1=%d B2=%d", joint_velocity_command_[0],velocity,wbuff[0],wbuff[1]);

    if(left_prev_cmd!=velocity)
    {
	    result = left_motor.writeData(wbuff,2);
	    //ROS_INFO("Writen successfully result=%d", result);
	    left_prev_cmd=velocity;
    }
    
    velocity=(int)angles::to_degrees(joint_velocity_command_[1]);
	wbuff[0]=velocity;
    wbuff[1]=velocity >> 8;
	//ROS_INFO("joint_velocity_command_[0]=%.2f velocity=%d  B1=%d B2=%d", joint_velocity_command_[0],velocity,wbuff[0],wbuff[1]);

    if(right_prev_cmd!=velocity)
    {
	    result = right_motor.writeData(wbuff,2);
	    //ROS_INFO("Writen successfully result=%d", result);
	    right_prev_cmd=velocity;
    }


		
}



int main(int argc, char** argv)
{
    ros::init(argc, argv, "mobile_robot_hardware_interface");
    ros::NodeHandle nh;
    //ros::AsyncSpinner spinner(4);  
    ros::MultiThreadedSpinner spinner(2); // Multiple threads for controller service callback and for the Service client callback used to get the feedback from ardiuno
    ROBOTHardwareInterface ROBOT(nh);
    //spinner.start();
    spinner.spin();
    //ros::spin();
    return 0;
}
